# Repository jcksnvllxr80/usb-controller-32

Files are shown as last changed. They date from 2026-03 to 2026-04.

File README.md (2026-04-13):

# USB Controller 32

A USB HID gamepad controller built on the **PIC32MX250F128B** microcontroller. The firmware reads button inputs from GPIO pins, two potentiometers on the PIC32 ADC, and an **MCP23017** I2C I/O expander, then reports them to a host PC as a standard USB HID gamepad. The board-level serial path uses a **MAX3232** level shifter, and the MCU clock is provided by a **20 MHz crystal**. Built with **MPLAB Harmony 3**, **FreeRTOS**, and **C++**.

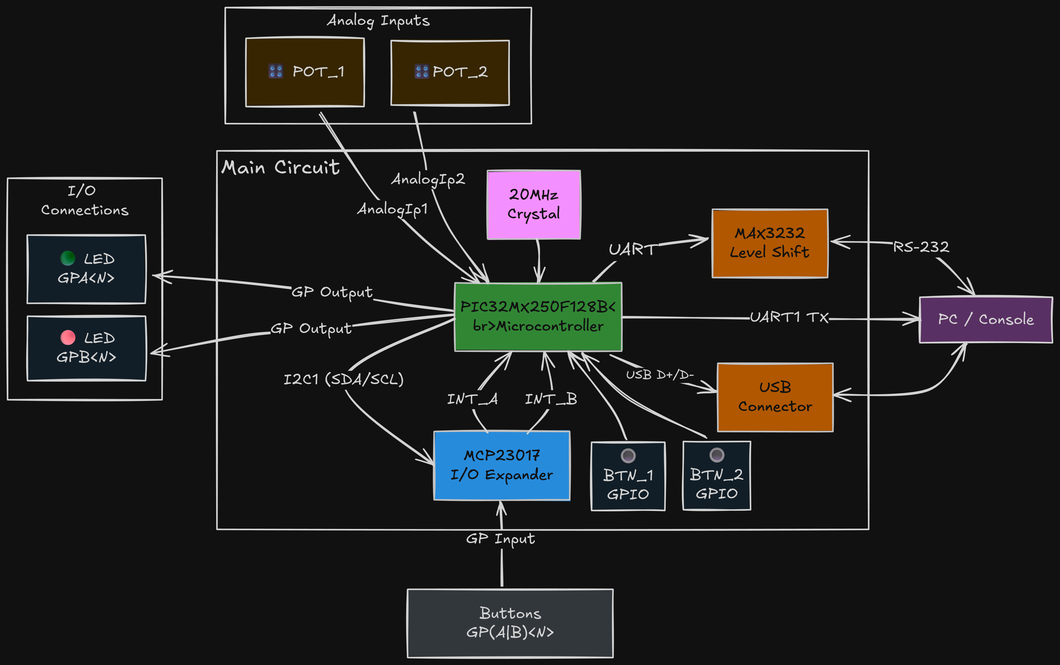
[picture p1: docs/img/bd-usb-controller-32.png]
Block Diagram


## Features

- USB HID gamepad with 18 button inputs (2 direct GPIO + 16 via MCP23017)
- 8-byte HID input report with 18 buttons, hat switch, and two live analog axes
- MCP23017 I2C I/O expander with interrupt-driven input detection
- MAX3232-backed debug serial / RS-232 path
- `POT_1` and `POT_2` sampled on `AN4` / `AN5` for `Z` and `Rz`
- Send-on-change HID reports for buttons and potentiometer axes
- Rate-limited serial logging for potentiometer changes with `POT_1` / `POT_2` identification
- FreeRTOS-based task scheduling
- UART debug logging and USB/HID diagnostics
- Green and red status LEDs

## Hardware Used

Main ICs and timing parts on this design:

- `PIC32MX250F128B` - main microcontroller, USB device controller, ADC, GPIO, I2C, and UART
- `MCP23017` - 16-bit I2C GPIO expander for the additional button inputs
- `MAX3232` - UART level shifter for the board's serial / RS-232 debug path
- `20 MHz crystal` - external clock source for the PIC32MX250F128B
- `2x linear potentiometers` - analog controls for `POT_1` and `POT_2`, mapped to HID `Z` and `Rz`
- `Mini USB breakout` - USB connector breakout for the device port, such as the small Adafruit mini USB breakout the board is using

## Architecture

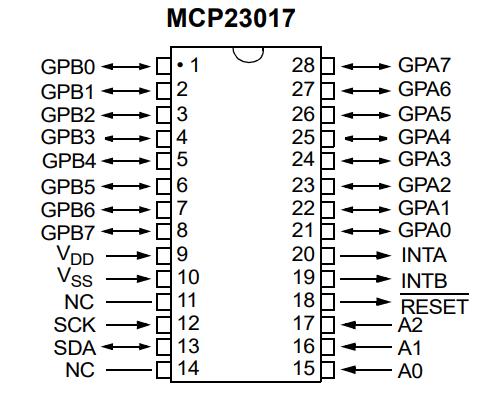
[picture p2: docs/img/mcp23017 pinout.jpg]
MCP23017 Pinout


### UML Class Diagram

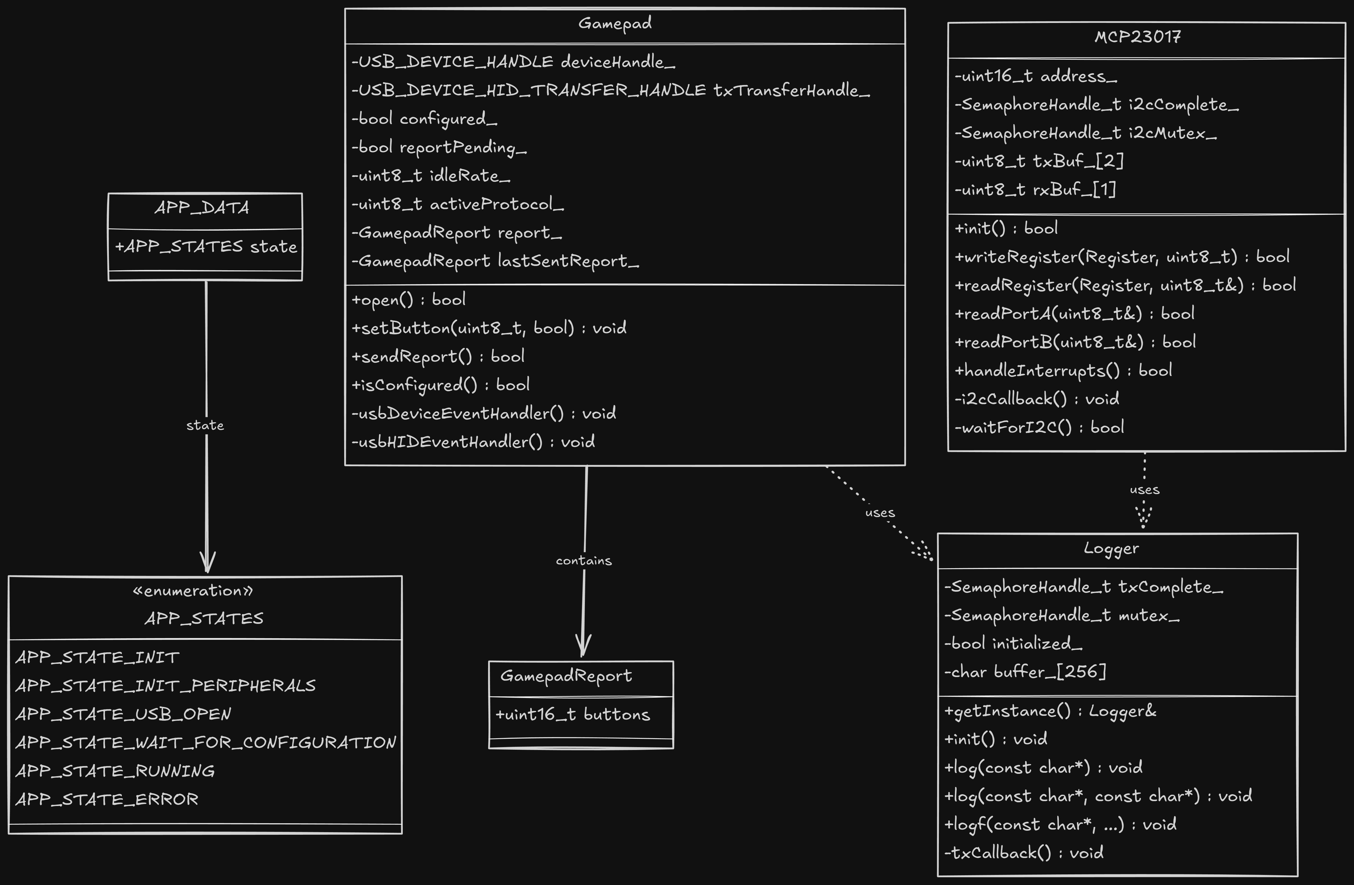
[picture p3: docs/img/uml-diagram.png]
UML Diagram


### State Machine

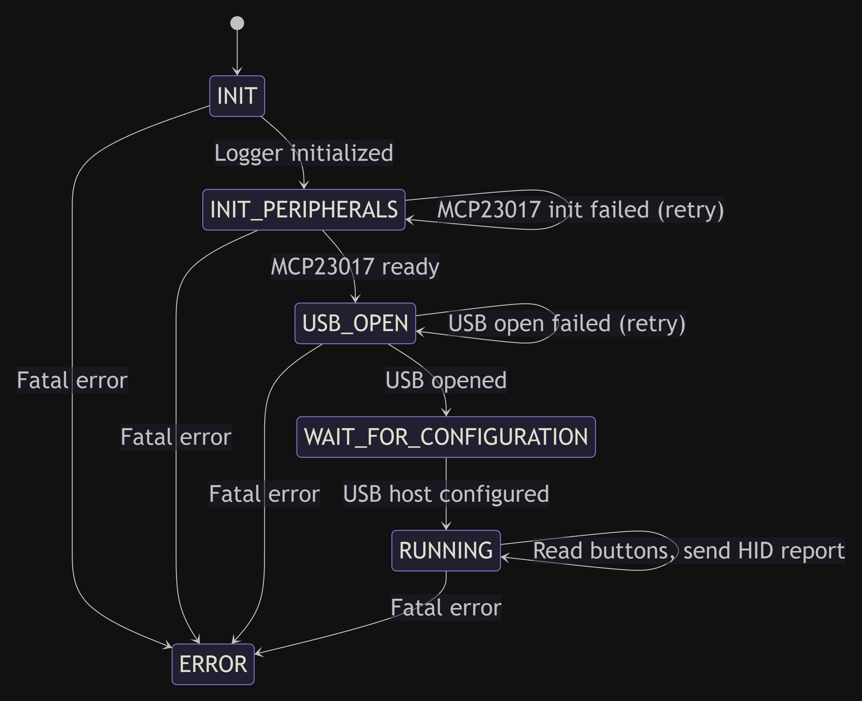
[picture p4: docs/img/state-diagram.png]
State Diagram


## Pin Assignment Table

### PIC32MX250F128B Direct I/O

| Signal | Pin | Port | Direction | Description |
|---|---|---|---|---|
| MCLR | 1 | — | Input | Master clear (active-low reset); 10k pull-up to VDD; PICkit 5 pin 1 (VPP) |
| PGED1 | 2 | RA0 | Programming | ICSP data (PICkit 5 pin 4) |
| PGEC1 | 3 | RA1 | Programming | ICSP clock (PICkit 5 pin 5) |
| GREEN_LED | 4 | RB0 | Output | Green status LED |
| RED_LED | 5 | RB1 | Output | Red status LED |
| POT_1 | 6 | RB2 / AN4 | Input | Analog potentiometer mapped to HID Z axis |
| POT_2 | 7 | RB3 / AN5 | Input | Analog potentiometer mapped to HID Rz axis |
| VSS | 8 | — | Power | Ground |
| OSC1 | 9 | RA2 | Input | 20 MHz crystal input |
| OSC2 | 10 | RA3 | Output | 20 MHz crystal output |
| U1TX | 11 | RB4 | Output | UART1 transmit (debug) |
| U1RX | 12 | RA4 | Input | UART1 receive (debug) |
| VDD | 13 | — | Power | 5V supply |
| INTERRUPT_A | 14 | RB5 | Input | MCP23017 Port A interrupt (active-low) |
| VBUS | 15 | — | Power | USB 5V bus voltage; connected to VCC |
| INTERRUPT_B | 16 | RB7 | Input | MCP23017 Port B interrupt (active-low) |
| SCL1 | 17 | RB8 | Output | I2C1 clock to MCP23017 |
| SDA1 | 18 | RB9 | Bidirectional | I2C1 data to MCP23017 |
| VSS | 19 | — | Power | Ground |
| VCAP | 20 | — | Power | Internal core regulator output; 0.1µF cap to VSS |
| D+ | 21 | — | Bidirectional | USB data plus |
| D− | 22 | — | Bidirectional | USB data minus |
| VUSB3V3 | 23 | — | Power | USB 3.3V supply; decoupling capacitors to GND |
| RB13 | 24 | RB13 | NC | Not connected |
| BUTTON_1 | 25 | RB14 | Input | Direct button input 1 |
| BUTTON_2 | 26 | RB15 | Input | Direct button input 2 |
| AVSS | 27 | — | Power | Analog ground |
| AVDD | 28 | — | Power | 5V analog supply |

### MCP23017 I/O Expander (I2C address 0x20)

| Port | Pins | Direction | Pull-ups | Interrupt | Description |
|---|---|---|---|---|---|
| Port A | GPA0–GPA7 | Input | Enabled | Enabled (interrupt-on-change) | 8 button inputs |
| Port B | GPB0–GPB7 | Input | Enabled | Enabled (interrupt-on-change) | 8 button inputs |

### Input/Output Summary

| Type | Count | Source | Details |
|---|---|---|---|
| Button inputs (direct) | 2 | PIC32 GPIO | RB14, RB15 |
| Button inputs (expanded) | 16 | MCP23017 Port A & B | GPA0–7, GPB0–7 |
| Analog inputs | 2 | PIC32 ADC | POT_1 on AN4 drives HID Z, POT_2 on AN5 drives HID Rz |
| LED outputs | 2 | PIC32 GPIO | Green (RB0), Red (RB1) |
| USB HID | 1 | USB peripheral | 18 buttons, hat switch, X/Y centered, live Z/Rz in an 8-byte report |
| Debug UART | 1 | UART1 via MAX3232 | 115200 baud debug/serial path (TX: RB4, RX: RA4) |
| I2C bus | 1 | I2C1 | MCP23017 at 0x20 |

## Getting Started

### Prerequisites

- [MPLAB X IDE](https://www.microchip.com/mplab/mplab-x-ide) or the **MPLAB Extension for VS Code**
- [XC32 Compiler](https://www.microchip.com/xc32) (v4.x or later)
- [PIC32MX DFP](https://packs.download.microchip.com/) v1.6.369
- **PICkit 5** (or compatible Microchip programmer/debugger)
- Git

### Install MPLAB for VS Code

1. Open **VS Code** (or VS Code Insiders).
2. Go to the **Extensions** view (`Ctrl+Shift+X`).
3. Search for **"MPLAB"** and install the **Microchip MPLAB** extension pack.
4. The extension will prompt you to install the **XC32 compiler** and required device packs if they are not found. Follow the prompts.
5. Restart VS Code after installation.

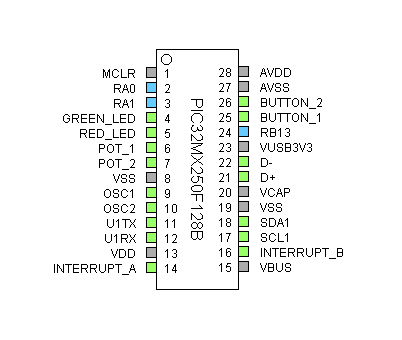
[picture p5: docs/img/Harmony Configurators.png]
Harmony Configurators


### Clone and Build

```bash
git clone https://github.com/jcksnvllxr80/usb-controller-32.git
cd usb-controller-32
```

1. Open the folder in VS Code.
2. The MPLAB extension should detect the project automatically via the CMake configuration in the `cmake/` directory.
3. Select the **usb-controller-32** project and the **default** configuration from the MPLAB project view.
4. Click **Build** (or press `Ctrl+Shift+B`).

### Program the Device

1. Connect the **PICkit 5** to the ICSP header on your board (ensure correct pin 1 orientation).
2. In the MPLAB extension, select **PICkit 5** as the hardware tool.
3. Set the programming speed to **Low** if you encounter connection issues.
4. Click **Program** to flash the `.hex` file to the PIC32MX250F128B.

> Warning: Use a native **USB 2.0** port when connecting this controller to the PC. On some machines, USB 3.x ports/controllers can fail enumeration or produce a Windows Code 10 error with this hardware. If your machine does not have a USB 2.0 port, connect the controller through a **USB 2.0 hub**.

### Verify Operation

1. After programming, the device should enumerate as a USB HID gamepad on the host PC.
2. Open **Set up USB game controllers** (Windows) or a gamepad tester to confirm button presses and `Z` / `Rz` potentiometer movement are registered.
3. Connect a serial terminal (115200 baud, 8N1) to UART1 to view debug logs, potentiometer change logs, and issue commands.

## UART Diagnostics

Helper scripts:

- `powershell -ExecutionPolicy Bypass -File .\tools\uart_query.ps1`
- `powershell -ExecutionPolicy Bypass -File .\tools\uart_cmd.ps1 -cmd "status"`

Useful commands:

- `status` - GPIO, USB, and LED summary
- `usb` - USB device state and register dump
- `enum` - enumeration counters and last setup request
- `hid` - HID readiness, send counters, and current report bytes
- `usblog` - recent USB transaction log
- `usbdbg` - toggle live USB debug logging
- `usbreset` - soft detach/reattach to force re-enumeration

Automatic serial logs:

- Potentiometer changes are logged automatically as `[POT] POT_1 axis=...` and/or `[POT] POT_2 axis=...`
- Logs are only emitted when the scaled axis value changes
- Pot logs are rate-limited to 5 lines per second total

## Firmware Notes

- GPIO and MCP23017 interrupts only latch state. HID reports are built and sent from `APP_Tasks()`.
- `POT_1` and `POT_2` are polled in `APP_Tasks()`, scaled from 10-bit ADC samples to 8-bit HID axis values, and mapped to HID `Z` and `Rz`.
- Potentiometer state is cached, so a new HID report is only queued when a button changes or when the last-sent `Z` / `Rz` byte changes.
- Potentiometer serial logs identify which input changed (`POT_1`, `POT_2`, or both), skip repeated values, and are rate-limited to 5 lines per second.
- HID reports are only queued when button or axis state changes, which keeps traffic and debug noise down.

## Project Structure

```
usb-controller-32/
├── cmake/                      # CMake build configurations
├── docs/                       # Datasheets, block diagram, images
├── tools/                      # Flash and UART helper scripts
├── usb-controller-32/
│   ├── mcc/                    # MPLAB Code Configurator files
│   └── src/
│       ├── main.cpp            # Entry point (SYS_Initialize + SYS_Tasks)
│       ├── app.cpp / app.h     # App task, GPIO/MCP state, USB HID send path
│       ├── command_handler.cpp / .h # UART command parser and diagnostics
│       ├── gamepad.cpp / .h    # USB HID gamepad driver
│       ├── mcp23017.cpp / .h   # MCP23017 I2C I/O expander driver
│       ├── logger.cpp / .h     # UART debug logger (singleton)
│       ├── usb_debug.c / .h    # USB debug logging helpers
│       ├── config/             # Harmony-generated peripheral config
│       └── third_party/rtos/   # FreeRTOS source
└── README.md
```

## Sponsor

PCB prototyping for this project is sponsored by [PCBWay](https://www.pcbway.com/).

PCBWay makes it easy to go from design files to manufactured boards. Upload your Gerber files, pick your board specs (layers, thickness, surface finish, color, etc.), and get an instant quote. Orders typically ship within a few days. Their online ordering process is straightforward — just create an account, upload your files, review the specs, and check out.

## License

See Microchip's license terms in the source file headers.

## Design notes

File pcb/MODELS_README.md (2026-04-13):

# KiCad Component Library — PIC32 USB Device Project

---

## 1. Adafruit Mini-B USB Breakout

| File | Purpose |
|---|---|
| `USB_MiniB_Adafruit_Breakout.kicad_sym` | Schematic symbol (KiCad 7+) |
| `USB_MiniB_Adafruit_Breakout.kicad_mod` | PCB footprint (KiCad 7+) |

### Installation
1. **Symbol Editor** → **File > Add Library** → select `USB_MiniB_Adafruit_Breakout.kicad_sym`
2. **Footprint Editor** → **File > Add Library** → select the folder containing `USB_MiniB_Adafruit_Breakout.kicad_mod`

### Pin Map
| Pin | Signal | Notes |
|-----|---|---|
| 1 | GND | Ground |
| 2 | ID | OTG ID — leave NC for device mode |
| 3 | D+ | USB data + |
| 4 | D− | USB data − |
| 5 | VBUS | +5 V from USB host |
| MP1/MP2 | Shell | Mechanical tabs (right side) — tie to GND pour |

### Footprint Dimensions (datasheet File No. 719)
- Signal pad pitch: **0.8 mm**, size: **0.5 × 1.6 mm**
- Shell pad size: **1.8 × 3.0 mm** at ±3.40 mm from centre
- Courtyard: **9.90 × 5.50 mm**
- Layout tolerance: ±0.05 mm

---

## 2. Crystal — HC-49/U Vertical, 20 MHz

| Property | Value |
|---|---|
| Symbol | `Device:Crystal` |
| Footprint | `Crystal_HC49-U_Vertical_20MHz:Crystal_HC49-U_Vertical_20MHz` |

### Installation
KiCad built-in library — no additional installation needed.

### Pin Map
| Pin | Signal | Notes |
|-----|---|---|
| 1 | XIN | To OSC1 / CLKI on PIC32 |
| 2 | XOUT | To OSC2 / CLKO on PIC32 |

### Footprint Dimensions
- Package: **HC-49/U** through-hole vertical
- Pin pitch: **4.88 mm**
- Lead diameter: **0.46 mm** (drill **0.6 mm**)
- Body: **3.68 mm W × 10.16 mm H** (above board)
- Courtyard: **6.2 × 13.0 mm**

---

## 3. PIC32MX250F128B

| Property | Value |
|---|---|
| Symbol | `MCU_Microchip_PIC32:PIC32MX250F128B-xSP` |
| Footprint | `Package_DIP:DIP-28_W7.62mm` |

### Installation
KiCad built-in library — no additional installation needed.

### Pin Map (DIP-28)
| Pin | Signal | Notes |
|-----|---|---|
| 1 | MCLR | Pull to 3.3 V via 10 kΩ; program header |
| 2–3 | AN0/AN1 | Analog or GPIO |
| 4–5 | OSC1/OSC2 | Crystal connections |
| 6 | SOSCI | Secondary osc in — leave NC if unused |
| 7 | SOSCO | Secondary osc out — leave NC if unused |
| 9 | VBUS | USB VBUS sense |
| 10 | D− | USB D− (direct — no series resistor needed on MX250) |
| 11 | D+ | USB D+ |
| 13 | VCAP | LDO filter cap — 10 µF to GND, **no other load** |
| 14 | AVDD | Analog supply — 3.3 V, decouple 100 nF |
| 15 | AVSS | Analog ground |
| 19 | SCL1 | I2C clock (4.7 kΩ pull-up to 3.3 V) |
| 18 | SDA1 | I2C data (4.7 kΩ pull-up to 3.3 V) |
| 22 | U1TX | UART TX → MAX3232 T1IN |
| 21 | U1RX | UART RX ← MAX3232 R1OUT |
| 8, 17, 28 | VDD | 3.3 V — decouple 100 nF per pin |
| 8, 20, 27 | VSS | Ground |

### Footprint Dimensions
- Package: **DIP-28**, row spacing **7.62 mm**
- Pin pitch: **2.54 mm**
- Drill: **0.8 mm**, pad: **1.6 mm**
- Courtyard: **33.0 × 10.16 mm**

---

## 4. MAX3232 RS232 Level Shifter

| Property | Value |
|---|---|
| Symbol | `Interface_UART:MAX3232` |
| Footprint | `Package_DIP:DIP-16_W7.62mm` |

### Installation
KiCad built-in library — no additional installation needed.

### Pin Map (DIP-16)
| Pin | Signal | Notes |
|-----|---|---|
| 1 | C1+ | Charge pump cap — 100 nF to C1− (pin 3) |
| 2 | V+ | Charge pump output — 100 nF to GND |
| 3 | C1− | Charge pump cap — see pin 1 |
| 4 | C2+ | Charge pump cap — 100 nF to C2− (pin 5) |
| 5 | C2− | Charge pump cap — see pin 4 |
| 6 | V− | Charge pump output — 100 nF to GND |
| 7 | T2OUT | RS232 TX channel 2 out |
| 8 | R2IN | RS232 RX channel 2 in |
| 9 | R2OUT | TTL RX channel 2 out |
| 10 | T2IN | TTL TX channel 2 in |
| 11 | T1IN | TTL TX in ← PIC32 U1TX |
| 12 | R1OUT | TTL RX out → PIC32 U1RX |
| 13 | R1IN | RS232 RX in ← cable TX |
| 14 | T1OUT | RS232 TX out → cable RX |
| 15 | GND | Ground |
| 16 | VCC | 3.3 V supply — decouple 100 nF to GND |

### Footprint Dimensions
- Package: **DIP-16**, row spacing **7.62 mm**
- Pin pitch: **2.54 mm**
- Drill: **0.8 mm**, pad: **1.6 mm**
- Courtyard: **20.32 × 10.16 mm**

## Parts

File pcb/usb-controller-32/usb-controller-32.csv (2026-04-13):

Reference | Qty | Value | DNP | Exclude from BOM | Exclude from Board | Footprint | Datasheet
C1,C2,C3,C4,C5,C6,C7,C8,C9,C10,C11,C12,C13,C14,C15,C16,C17,C18,C19,C20,C21,C24,C25,C26,C27 | 25 | 0.1µF |  |  |  | Capacitor_THT:C_Disc_D5.0mm_W2.5mm_P2.50mm
C22,C23 | 2 | 0.01µF |  |  |  | Capacitor_THT:C_Disc_D5.0mm_W2.5mm_P2.50mm
D1 | 1 | LED_Dual_AAK |  |  |  | LED_THT:LED_D5.0mm-3
J1 | 1 | USB_MiniB_Adafruit_Breakout |  |  |  | extra:USB_MiniB_Adafruit_Breakout | https://www.adafruit.com/product/1764
J2 | 1 | Conn_01x08_Pin |  |  |  | Connector_PinHeader_2.54mm:PinHeader_1x08_P2.54mm_Vertical
J3 | 1 | Conn_01x03_Pin |  |  |  | Connector_PinHeader_2.54mm:PinHeader_1x03_P2.54mm_Vertical
R1,R2,R3,R4,R5,R6,R7,R8,R9,R10,R11,R12,R13,R14,R15,R16,R17,R18,R19,R20,R21,R22,R23,R24,R25,R26,R27,R28,R29,R30,R31,R32 | 32 | 12k |  |  |  | Resistor_THT:R_Axial_DIN0207_L6.3mm_D2.5mm_P10.16mm_Horizontal
R33 | 1 | 8.2k |  |  |  | Resistor_THT:R_Axial_DIN0207_L6.3mm_D2.5mm_P10.16mm_Horizontal
R34 | 1 | 1.2k |  |  |  | Resistor_THT:R_Axial_DIN0207_L6.3mm_D2.5mm_P10.16mm_Horizontal
R35 | 1 | 10k |  |  |  | Resistor_THT:R_Axial_DIN0207_L6.3mm_D2.5mm_P10.16mm_Horizontal
R36,R37 | 2 | 4.7k |  |  |  | Resistor_THT:R_Axial_DIN0207_L6.3mm_D2.5mm_P10.16mm_Horizontal
R38 | 1 | 15k |  |  |  | Resistor_THT:R_Axial_DIN0207_L6.3mm_D2.5mm_P10.16mm_Horizontal
RV1,RV2 | 2 | R_Potentiometer |  |  |  | Potentiometer_THT:Potentiometer_Bourns_3386P_Vertical
SW1,SW2,SW3,SW4,SW5,SW6,SW7,SW8,SW9,SW10,SW11,SW12,SW13,SW14,SW15,SW16,SW17,SW18 | 18 | SW_Push_Dual |  |  |  | Button_Switch_THT:SW_TH_Tactile_Omron_B3F-100x
U1 | 1 | PIC32MX250F128B |  |  |  | Package_DIP:DIP-28_W7.62mm | http://ww1.microchip.com/downloads/en/DeviceDoc/PIC32MX1XX2XX-28-36-44-PIN-DS60001168K.pdf
U2 | 1 | MAX3232 |  |  |  | Package_DIP:DIP-16_W7.62mm | https://www.analog.com/media/en/technical-documentation/data-sheets/max3222-max3241.pdf
U3 | 1 | MCP23017x-x-SP |  |  |  | Package_DIP:DIP-28_W7.62mm | https://ww1.microchip.com/downloads/aemDocuments/documents/APID/ProductDocuments/DataSheets/MCP23017-Data-Sheet-DS20001952.pdf
Y1 | 1 | 20MHz |  |  |  | extra:Crystal_HC49-U_Vertical_20MHz

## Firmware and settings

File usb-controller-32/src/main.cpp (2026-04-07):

#include <stddef.h>
#include <stdbool.h>
#include <stdlib.h>
#include "definitions.h"

int main(void)
{
    /* Initialize all modules (including APP_Initialize and USB) */
    SYS_Initialize(NULL);

    /* Create RTOS tasks (USB + App) and start the scheduler — never returns */
    SYS_Tasks();

    return EXIT_FAILURE;
}

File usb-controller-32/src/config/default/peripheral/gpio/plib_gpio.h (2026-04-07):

/*******************************************************************************
  GPIO PLIB

  Company:
    Microchip Technology Inc.

  File Name:
    plib_gpio.h

  Summary:
    GPIO PLIB Header File

  Description:
    This library provides an interface to control and interact with Parallel
    Input/Output controller (GPIO) module.

*******************************************************************************/

/*******************************************************************************
* Copyright (C) 2019 Microchip Technology Inc. and its subsidiaries.
*
* Subject to your compliance with these terms, you may use Microchip software
* and any derivatives exclusively with Microchip products. It is your
* responsibility to comply with third party license terms applicable to your
* use of third party software (including open source software) that may
* accompany Microchip software.
*
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
* IN NO EVENT WILL MICROCHIP BE LIABLE FOR ANY INDIRECT, SPECIAL, PUNITIVE,
* INCIDENTAL OR CONSEQUENTIAL LOSS, DAMAGE, COST OR EXPENSE OF ANY KIND
* WHATSOEVER RELATED TO THE SOFTWARE, HOWEVER CAUSED, EVEN IF MICROCHIP HAS
* BEEN ADVISED OF THE POSSIBILITY OR THE DAMAGES ARE FORESEEABLE. TO THE
* FULLEST EXTENT ALLOWED BY LAW, MICROCHIP'S TOTAL LIABILITY ON ALL CLAIMS IN
* ANY WAY RELATED TO THIS SOFTWARE WILL NOT EXCEED THE AMOUNT OF FEES, IF ANY,
* THAT YOU HAVE PAID DIRECTLY TO MICROCHIP FOR THIS SOFTWARE.
*******************************************************************************/

#ifndef PLIB_GPIO_H
#define PLIB_GPIO_H

#include <device.h>
#include <stdint.h>
#include <stdbool.h>
#include <stddef.h>

// DOM-IGNORE-BEGIN
#ifdef __cplusplus  // Provide C++ Compatibility

    extern "C" {

#endif
// DOM-IGNORE-END

// *****************************************************************************
// *****************************************************************************
// Section: Data types and constants
// *****************************************************************************
// *****************************************************************************


/*** Macros for GREEN_LED pin ***/
#define GREEN_LED_Set()               (LATBSET = (1<<0))
#define GREEN_LED_Clear()             (LATBCLR = (1<<0))
#define GREEN_LED_Toggle()            (LATBINV= (1<<0))
#define GREEN_LED_OutputEnable()      (TRISBCLR = (1<<0))
#define GREEN_LED_InputEnable()       (TRISBSET = (1<<0))
#define GREEN_LED_Get()               ((PORTB >> 0) & 0x1)
#define GREEN_LED_GetLatch()          ((LATB >> 0) & 0x1)
#define GREEN_LED_PIN                  GPIO_PIN_RB0

/*** Macros for RED_LED pin ***/
#define RED_LED_Set()               (LATBSET = (1<<1))
#define RED_LED_Clear()             (LATBCLR = (1<<1))
#define RED_LED_Toggle()            (LATBINV= (1<<1))
#define RED_LED_OutputEnable()      (TRISBCLR = (1<<1))
#define RED_LED_InputEnable()       (TRISBSET = (1<<1))
#define RED_LED_Get()               ((PORTB >> 1) & 0x1)
#define RED_LED_GetLatch()          ((LATB >> 1) & 0x1)
#define RED_LED_PIN                  GPIO_PIN_RB1

/*** Macros for POT_1 pin ***/
#define POT_1_Get()               ((PORTB >> 2) & 0x1)
#define POT_1_GetLatch()          ((LATB >> 2) & 0x1)
#define POT_1_PIN                  GPIO_PIN_RB2

/*** Macros for POT_2 pin ***/
#define POT_2_Get()               ((PORTB >> 3) & 0x1)
#define POT_2_GetLatch()          ((LATB >> 3) & 0x1)
#define POT_2_PIN                  GPIO_PIN_RB3

/*** Macros for INTERRUPT_A pin ***/
#define INTERRUPT_A_Set()               (LATBSET = (1<<5))
#define INTERRUPT_A_Clear()             (LATBCLR = (1<<5))
#define INTERRUPT_A_Toggle()            (LATBINV= (1<<5))
#define INTERRUPT_A_OutputEnable()      (TRISBCLR = (1<<5))
#define INTERRUPT_A_InputEnable()       (TRISBSET = (1<<5))
#define INTERRUPT_A_Get()               ((PORTB >> 5) & 0x1)
#define INTERRUPT_A_GetLatch()          ((LATB >> 5) & 0x1)
#define INTERRUPT_A_PIN                  GPIO_PIN_RB5
#define INTERRUPT_A_InterruptEnable()   (CNENBSET = (1<<5))
#define INTERRUPT_A_InterruptDisable()  (CNENBCLR = (1<<5))

/*** Macros for INTERRUPT_B pin ***/
#define INTERRUPT_B_Set()               (LATBSET = (1<<7))
#define INTERRUPT_B_Clear()             (LATBCLR = (1<<7))
#define INTERRUPT_B_Toggle()            (LATBINV= (1<<7))
#define INTERRUPT_B_OutputEnable()      (TRISBCLR = (1<<7))
#define INTERRUPT_B_InputEnable()       (TRISBSET = (1<<7))
#define INTERRUPT_B_Get()               ((PORTB >> 7) & 0x1)
#define INTERRUPT_B_GetLatch()          ((LATB >> 7) & 0x1)
#define INTERRUPT_B_PIN                  GPIO_PIN_RB7
#define INTERRUPT_B_InterruptEnable()   (CNENBSET = (1<<7))
#define INTERRUPT_B_InterruptDisable()  (CNENBCLR = (1<<7))
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

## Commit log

2026-03-17 Add configuration settings and update component positions in YAML files
    [configuration.h]
2026-03-17 Update GPIO macros and add BUTTON_1, BUTTON_2, INTERRUPT_A, and INTERRUPT_B definitions
2026-03-17 Add CHANGE_NOTICE interrupt handling and GPIO callback support
2026-03-17 Implement GPIO interrupt handling and update button state management
2026-03-17 Fix button press detection logic and add logging for button state changes and MCP23017 interrupts
    [app.cpp]
2026-03-22 change the i2c brg to 400khz from 50khz
2026-04-07 WIP start over (#1)
    * remove everything except uart and buttons
    * Refactor button handling logic to use interrupt callbacks and improve state tracking
    * Add pull-up resistors for PORTB and update button logging
    * Fix UART write handling in Logger to ensure txDone_ is set correctly on failure
    * add i2c1
    * mcp23017 works properly
    * add max3232cpe datasheet
    * Update USB Controller configuration and image
    - Updated the mcc-config.mc4 file to include the i2c1 module in the USB controller configuration.
    - Modified the bd-usb-controller-32.png image file.
    * get the buttons working
    [configuration.h]
2026-04-07 Implement USB attach delay and improve USB detachment handling
2026-04-07 Refactor USB device initialization and improve HID handling
2026-04-07 feat: Update block diagram and add potentiometer support to USB controller
    - Changed background colors in the block diagram for better visibility.
    - Added new elements to the block diagram, including analog inputs and potentiometers.
    - Updated the USB controller application to include potentiometer reading and logging.
    - Introduced a new GamepadReport structure to handle gamepad data more effectively.
    - Implemented ADC initialization and reading functions for potentiometers.
    - Enhanced command handler to log potentiometer values.
    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
2026-04-07 fix: update MCP23017 bank LEDs to reflect any active input
    [mcp23017.cpp]
2026-04-08 fix microcontroller pin table in readme
2026-04-13 Feature/pcb (#2)
    * add pcb project
    * add mini b usb module footprint and sch
    * add adafruit usb mini-b model and footprint
    * update adafruit breakout footprint and model
    * - finish schematic
    - add BOM
    * add all footprints to PCB
    * add claude generated python script to layout pcb
    add resulting pcb of aformentioned script run
    * use different crystal footprint
    * update pcb
    replace led footprint with gnd in middle
    * add routed pcb
    * resolve DRC errors and create fabouts
    [usb-controller-32-B_Cu.gbr, usb-controller-32-B_Mask.gbr, usb-controller-32-B_Paste.gbr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]
2026-04-13 add pcbway shoutout
2026-04-13 change via size to 0.2mm drill hole with 0.4mm diameter (#3)
    [usb-controller-32-B_Cu.gbr, usb-controller-32-B_Mask.gbr, usb-controller-32-B_Paste.gbr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]
